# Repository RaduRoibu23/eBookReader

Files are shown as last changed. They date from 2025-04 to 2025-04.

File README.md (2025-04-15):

#  OpenBook E-Reader
---

## Prezentare Generala

**OpenBook** este un e-reader open-source, proiectat in jurul microcontrollerului **ESP32-C6**, gandit pentru eficienta energetica, modularitate si conectivitate moderna. Dispozitivul utilizeaza un ecran e-paper de **7.5”**, asa cum a fost ceurt in enunt.

Proiectul a fost realizat in conformitate cu cerintele specifice [proiectului TSC 2025](https://ocw.cs.pub.ro/courses/tsc/proiect2025), punand accent pe documentare clara, organizare modulara si integrarea eficienta a componentelor hardware si software.

Am investit aproximativ **35–40 de ore de lucru** in dezvoltarea acestuia pentru a-l aduce in forma actuala, timp in care am proiectat schema electronica si PCB-ul . Din pacate, din cauza unor probleme tehnice peste care nu am reusit sa trec in timp util, **nu am reusit sa finalizez partea de modelare 3D** a carcasei si ansamblului complet.

In ciuda acestui neajuns, consider ca proiectul reflecta un efort solid si o abordare completa in ceea ce priveste realizarea.

Poza Bottom
Poza Top
Routing

---

##  Diagrama de Bloc
```

                +---------------------------+
                |     USB-C Connector       |
                | (USB Data ↔ ESP32 USB)    |
                | (ESD & Termination Prot.) |
                +-------------+-------------+
                              |
                              v
                +--------------------------+
                |       Charging IC        |<-- USB-C Power
                +-------------+------------+
                              |
                              v
                +--------------------------+
                |         Battery          |
                +-------------+------------+
                              |
                              v
                +--------------------------+
                |           LDO            |
                |       (3.3V Reg)         |
                +-------------+------------+
                              |
                              v
                      +--------------+
                      |    ESP32-C6   |
                      +------+--------+
                             |
      +----------------------+-------------------------+
      |                      |                         |
      v                      v                         v
+-----------+       +----------------+         +-----------------+
|  Display  |<----->|     BME688     |<------->| Tactile Buttons |
| (SPI 4W)  |       |   (I2C + PU)   |         |  (GPIO + RC)     |
+-----------+       +----------------+         +-----------------+
```
Legend:
- PU = Pull-up resistors
- RC = Debouncing circuit

---

##  Arhitectura Hardware

###  ESP32-C6-WROOM-1-N8

- **Rol:** Controler principal
- **Frecventa:** 160 MHz
- **Memorie:** 512KB SRAM + 8MB Flash
- **Conectivitate:** Wi-Fi 6, Bluetooth 5, USB 2.0
- **Interfete:**
  - SPI: Display, Flash, MicroSD
  - I2C: Senzori si RTC
  - UART: Debug
  - GPIO: Butoane si LED-uri

###  Display E-Paper

- **Dimensiune:** 7.5 inch
- **Rezolutie:** 800×480 px
- **Consum:** <50mA activ, ~0 in standby
- **Interfata:** SPI
- 
###  Sistem Alimentare

- **Baterie:** Li-Po 3.7V / 2500mAh
- **Incarcare:** USB-C (5V, max. 1A) – MCP73831
- **Monitorizare:** MAX17048 (prin I2C)
- **Consum estimat:**
  - Activ (Wi-Fi + Display): ~150mA
  - Standby: ~10mA
  - Deep Sleep: <50µA
- **Autonomie:** ~250 ore (~1 saptamana)

### Navigare

- **Butoane:** Panasonic EVQPUJ02K
- **Rezistenta pull-up:** 10KΩ

### USB-C

- **Rol:** Alimentare si transfer de date
- **Protectie:** Diode ESD (USBLC6-2SC6Y)

---

##  Configuratie Pini ESP32-C6

| Pin | Functie | Componenta | Descriere |
|---|---|---|---|
| GPIO0 | BOOT_BUTTON | Buton | Init bootloader |
| GPIO1 | RESET_BUTTON | Buton | Reset sistem |
| GPIO2 | CHANGE_BUTTON | Buton | Navigare meniuri |
| GPIO3 | EPD_CS | Display | SPI Chip Select |
| GPIO4 | EPD_DC | Display | Date / Comenzi |
| GPIO5 | EPD_RST | Display | Reset display |
| GPIO6 | EPD_BUSY | Display | Status refresh |
| GPIO7 | SPI_MOSI | Flash, SD, Display  | Date SPI |
| GPIO8 | SPI_MISO | Flash, SD, Display  | Date SPI (read) |
| GPIO9 | SPI_SCK | Flash, SD, Display  | Ceas SPI |
| GPIO10  | FLASH_CS | Flash | SPI Chip Select |
| GPIO11  | SD_CS | Card SD | SPI Chip Select |
| GPIO12  | I2C_SDA | Senzori, RTC | Date I2C |
| GPIO13  | I2C_SCL | Senzori, RTC | Ceas I2C |
| GPIO14  | CHG_LED | LED | Indicator incarcare |
| GPIO15  | UART_TX | Debug | Serial TX |
| GPIO16  | UART_RX | Debug | Serial RX |
| GPIO17  | USB_D+ | USB-C | Linie USB pozitiva |
| GPIO18  | USB_D- | USB-C | Linie USB negativa |

---

## BOM:

| **Piece Name** | **Piece Type (Optional)** | **Link** |
|---|---|---|
| ESP32-CAP C0402 | C | https://componentsearchengine.com/part-view/CC0402MRX5R5BB106/YAGEO |
| ADAFRUIT_CHIP-LED0603 | LED | https://www.snapeda.com/parts/KP-1608SURCK/Kingbright/view-part/?ref=search&t=LED%200603 |
| 112ATAARR03 | microSD | https://www.snapeda.com/parts/112A-TAAR-R03/Attend/view-part/ |
| 744043680 | L | https://eu.mouser.com/ProductDetail/Wurth-Elektronik/744043680?qs=PGXP4M47uW6VkZq%252BkzjrHA%3D%3D |
| BD5229G-TR | Voltage Detector | https://www.snapeda.com/parts/BD5229G-TR/Rohm/view-part/?ref=search&t=BD5229G-TR |
| BUTTON_CUSYOMV1 | Button | https://www.snapeda.com/search/?q=EVQP7L01P&search-type=parts |
| CPH3225A | C | https://www.snapeda.com/parts/CPH3225A/Seiko/view-part/ |
| DS3231SN# | I²C-Integrated RTC/TCXO/Crystal | https://www.snapeda.com/parts/DS3231SN%23/Analog%20Devices/view-part/?ref=search&t=DS3231SN%23 |
| ESP32-C6-WROOM-1-N8 | ESP32 | https://www.snapeda.com/parts/ESP32-C6-WROOM-1-N8/Espressif%20Systems/view-part/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 |
| ESP VARSISTOR | Varsistor (B72520T0350K062) | https://ro.mouser.com/ProductDetail/EPCOS-TDK/B72520T0350K062?qs=dEfas%2FXlABIszF52uu7vrg%3D%3D |
| ESP32_WROVER_AVX---SD0805S020S1R0 |  DIODE SCHOTTKY | https://componentsearchengine.com/part-view/SD0805S020S1R0/Kyocera%20AVX |
| ESP32_WROVER_BME680_BME680 | Env Senzor | https://www.snapeda.com/parts/BME680/Bosch%20Sensortec/view-part/?ref=search&t=bme680 |
| ESP32_WROVER_EAGLE-LTSPICE_R | R | https://componentsearchengine.com/part-view/R0402%201%25%20100%20K%20(RC0402FR-07100KL)/YAGEO |
| ESP32_WROVER_SPARKFUN-DISCRETESEMI_MOSFET_PCH | T DMG2305UX-7 | https://componentsearchengine.com/part-view/DMG2305UX-7/Diodes%20Incorporated |
| ESP32_WROVER_SPARKFUN-IC-POWER_MCP73831 | TINY INTEGRATED LI-ION/LI-POLY CHARGE MGNT CONTROLLER | https://componentsearchengine.com/part-view/MCP73831T-2ACI%2FOT/Microchip |
| FH34SRJ-24S-0.5SH_99_ | FH34SRJ-24S-0.5SH(99) | https://componentsearchengine.com/part-view/FH34SRJ-24S-0.5SH(99)/Hirose |
| MAX17048G+T10 |  Cell Fuel Gauge with ModelGauge | https://www.snapeda.com/parts/MAX17048G+T10/Analog%20Devices/view-part/ |
| MBR0530 |  Diode Schottky | https://www.snapeda.com/parts/MBR0530/Onsemi/view-part/ |
| PGB1010603MR |  Ipp Tvs Diode Surface Mount 0603 | https://www.snapeda.com/parts/PGB1010603MR/Littelfuse/view-part/ |
| QWIIC_CONNECTOR | PRT-14417 QWIIC_CONNECTOR | https://www.snapeda.com/parts/PRT-14417/SparkFun/view-part/ |
| RCL_CPOL-EU | C pol | https://grabcad.com/library/tantalum-smd-capacitor-type-b-3528-1 |
| SAMACSYS_PARTS_USB4110-GF-A | USB4110-GF-A | https://www.snapeda.com/parts/USB4110-GF-A./Global%20Connector%20Technology/view-part/ |
| SJ | Jumper-SolderPasteJumper3way | https://grabcad.com/library/solder-jumpers-1 |
| TP | Test-Pad | self-made |
| SI1308EDL-T1-GE3 |  MOSFET Transistor | https://www.snapeda.com/parts/SI1308EDL-T1-GE3/Vishay/view-part/ |
| USBLC6-2SC6Y |  Ipp Tvs Diode Surface Mount | https://www.snapeda.com/parts/USBLC6-2SC6Y/STMicroelectronics/view-part/?ref=dk&t=USBLC6-2SC6Y&con_ref=None |
| W25Q512JVEIQ | FLASH - NOR Memory | https://www.snapeda.com/parts/W25Q512JVEIQ/Winbond%20Electronics/view-part/?ref=search&t=W25Q512JVEIQ |
| XC6220A331MR-G | Voltage Regulator | https://ro.mouser.com/ProductDetail/Torex-Semiconductor/XC6220A331MR-G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

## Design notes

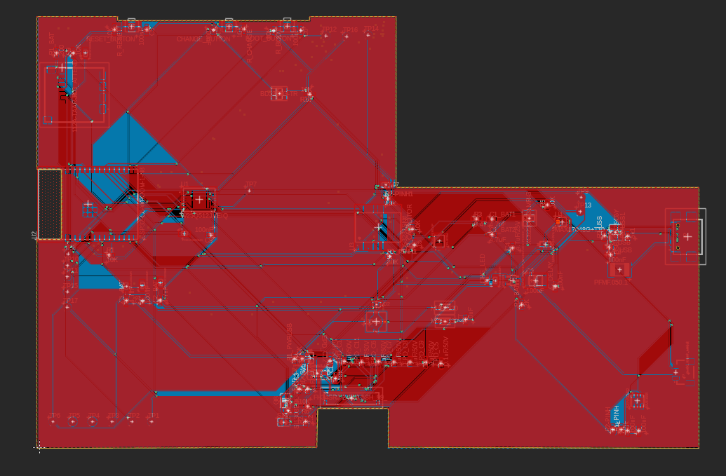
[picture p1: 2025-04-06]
Proiect TCS/Images/Poza Top.png

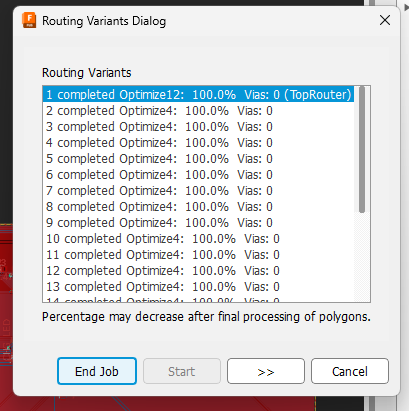
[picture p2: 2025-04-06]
Proiect TCS/Images/Routing .png

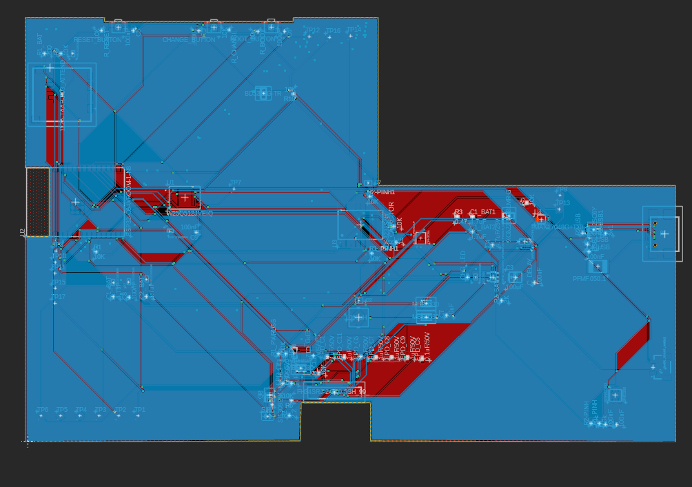
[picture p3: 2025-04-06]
Proiect TCS/Images/Poza Bottom.png

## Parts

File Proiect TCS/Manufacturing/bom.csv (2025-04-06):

Qty | Value | Device | Package | Parts | Description | ARROW_PART_NUMBER | ARROW_PRICE-STOCK | AVAILABILITY | CENTROID_NOT_SPECIFIED | CHECK_PRICES | COPYRIGHT | DATASHEET | DESCRIPTION | DIGIKEY_DESCRIPTION | DIGIKEY_PART_NUMBER | HEIGHT | LEAD_FREE | MANUFACTURER_NAME | MANUFACTURER_PART_NUMBER | MF | MFR_NAME | MOUSER_PART_NUMBER | MOUSER_PRICE-STOCK | MOUSER_TESTING_PART_NUMBER | MOUSER_TESTING_PRICE-STOCK | MP | MPN | PACKAGE | POPULARITY | PREFIX | PRICE | PROD_ID | PURCHASE-URL | ROHS | SNAPEDA_LINK | SPICEMODEL | SPICEPREFIX | TEMPERATURE_RANGE_HIGH | TEMPERATURE_RANGE_LOW | TP_SIGNAL_NAME | VALUE
1 |  | ADAFRUIT_LEDCHIP-LED0603 | ADAFRUIT_CHIP-LED0603 | CHG_LED | LED
1 |  | ESP32C6_VARISTORCN1812 | ESP32C6_VARISTOR_CT/CN1812 | PFMF.050.1 | VARISTOR |  |  |  |  |  |  |  |  |  |  |  |  |  |  |  |  |  |  |  |  |  |  |  | 0
1 |  | SAMACSYS_PARTS_USB4110-GF-A | SAMACSYS_PARTS_USB4110GFA | J2 | CONN USB 2.0 TYPE-C R/A SMT |  |  |  |  |  |  |  | CONN USB 2.0 TYPE-C R/A SMT |  |  | 3.26mm |  | GCT (GLOBAL CONNECTOR TECHNOLOGY) | USB4110-GF-A |  |  | 640-USB4110-GF-A | https://www.mouser.co.uk/ProductDetail/GCT/USB4110-GF-A?qs=KUoIvG%2F9IlYiZvIXQjyJeA%3D%3D
1 |  | SJ | SJ | SJ1 | SMD solder JUMPER |  |  |  |  |  |  |  |  |  |  |  |  |  |  |  |  |  |  |  |  |  |  |  | 3
1 | 0.1uF/50V | EAGLE-LTSPICE_CC0402 | EAGLE-LTSPICE_C0402 | EPD_C5 | CAPACITOR, European symbol |  |  |  |  |  |  |  |  |  |  |  |  |  |  |  |  |  |  |  |  |  |  |  |  |  |  |  |  |  |  | NONE | C
1 | 0.47 | ESP32_WROVER_EAGLE-LTSPICE_RR0402 | ESP32_WROVER_EAGLE-LTSPICE_R0402 | R3 | RESISTOR, European symbol |  |  |  |  |  |  |  |  |  |  |  |  |  |  |  |  |  |  |  |  |  |  |  |  |  |  |  |  |  |  | NONE | R
1 | 100K | ESP32_WROVER_EAGLE-LTSPICE_RR0402 | ESP32_WROVER_EAGLE-LTSPICE_R0402 | R1_PWRUSB | RESISTOR, European symbol |  |  |  |  |  |  |  |  |  |  |  |  |  |  |  |  |  |  |  |  |  |  |  |  |  |  |  |  |  |  | NONE | R
3 | 100nF | EAGLE-LTSPICE_CC0402 | EAGLE-LTSPICE_C0402 | C5, C6, C10 | CAPACITOR, European symbol |  |  |  |  |  |  |  |  |  |  |  |  |  |  |  |  |  |  |  |  |  |  |  |  |  |  |  |  |  |  | NONE | C
6 | 100nF | ESP32_WROVER_EAGLE-LTSPICE_CC0402 | ESP32_WROVER_EAGLE-LTSPICE_C0402 | C1, C2, C4_USB, C8, C9, C_DELAY | CAPACITOR, European symbol |  |  |  |  |  |  |  |  |  |  |  |  |  |  |  |  |  |  |  |  |  |  |  |  |  |  |  |  |  |  | NONE | C
1 | 100uF | RCL_CPOL-EUCT3528 | RCL_CT3528 | C3 | POLARIZED CAPACITOR, European symbol |  |  |  |  |  |  |  |  |  |  |  |  |  |  |  |  |  |  |  |  |  |  |  | 0 |  |  |  |  |  |  |  | C
14 | 10K | ESP32_WROVER_EAGLE-LTSPICE_RR0402 | ESP32_WROVER_EAGLE-LTSPICE_R0402 | R1, R1_PINH1, R2-PINH1, R4, R5, R6, R7, R8, R9, R10, R_BOOT, R_CHANGE, R_CL1, R_RESET | RESISTOR, European symbol |  |  |  |  |  |  |  |  |  |  |  |  |  |  |  |  |  |  |  |  |  |  |  |  |  |  |  |  |  |  | NONE | R
2 | 10k | ESP32_WROVER_EAGLE-LTSPICE_RR0402 | ESP32_WROVER_EAGLE-LTSPICE_R0402 | R1_PINH, R2-PINH | RESISTOR, European symbol |  |  |  |  |  |  |  |  |  |  |  |  |  |  |  |  |  |  |  |  |  |  |  |  |  |  |  |  |  |  | NONE | R
1 | 10uF | ESP32_WROVER_EAGLE-LTSPICE_CC0402 | ESP32_WROVER_EAGLE-LTSPICE_C0402 | C7 | CAPACITOR, European symbol |  |  |  |  |  |  |  |  |  |  |  |  |  |  |  |  |  |  |  |  |  |  |  |  |  |  |  |  |  |  | NONE | C
1 | 112A-TAAR-R03_ATTEND | 112A-TAAR-R03_ATTEND | 112ATAARR03ATTEND | J4 | Micro SD Card Socket, Push-Push Type, Top Mount, SMT, H=1.83mm, 10u |  |  |  |  |  |  |  | Micro SD Card Socket | Push-Push Type | Top Mount | SMT | H=1.83mm | 10u |  |  | 1.9mm |  | ATTEND | 112A-TAAR-R03 ATTEND
1 | 15 | ESP32_WROVER_EAGLE-LTSPICE_RR0402 | ESP32_WROVER_EAGLE-LTSPICE_R0402 | R_CAPACITOR | RESISTOR, European symbol |  |  |  |  |  |  |  |  |  |  |  |  |  |  |  |  |  |  |  |  |  |  |  |  |  |  |  |  |  |  | NONE | R
9 | 1uF/50V | EAGLE-LTSPICE_CC0402 | EAGLE-LTSPICE_C0402 | EPD_C1, EPD_C2, EPD_C6, EPD_C7, EPD_C8, EPD_C9, EPD_C10, EPD_C11, EPD_C12 | CAPACITOR, European symbol |  |  |  |  |  |  |  |  |  |  |  |  |  |  |  |  |  |  |  |  |  |  |  |  |  |  |  |  |  |  | NONE | C
1 | 2.2 | ESP32_WROVER_EAGLE-LTSPICE_RR0402 | ESP32_WROVER_EAGLE-LTSPICE_R0402 | R2 | RESISTOR, European symbol |  |  |  |  |  |  |  |  |  |  |  |  |  |  |  |  |  |  |  |  |  |  |  |  |  |  |  |  |  |  | NONE | R
1 | 200 | ESP32_WROVER_EAGLE-LTSPICE_RR0402 | ESP32_WROVER_EAGLE-LTSPICE_R0402 | R1_BAT | RESISTOR, European symbol |  |  |  |  |  |  |  |  |  |  |  |  |  |  |  |  |  |  |  |  |  |  |  |  |  |  |  |  |  |  | NONE | R
2 | 20V/4.2A/52mO/1.4W | ESP32_WROVER_SPARKFUN-DISCRETESEMI_MOSFET_PCH-DMG2305UX-7 | ESP32_WROVER_SPARKFUN-DISCRETESEMI_SOT23-3 | Q1, Q2 | P-channel MOSFETs |  |  |  |  |  |  |  |  |  |  |  |  |  |  |  |  |  |  |  |  |  |  |  |  |  |  | TRAN-14388 |  |  |  |  |  |  |  |  | 20V/4.2A/52mO/1.4W
1 | 2K | ESP32_WROVER_EAGLE-LTSPICE_RR0402 | ESP32_WROVER_EAGLE-LTSPICE_R0402 | R2_BAT | RESISTOR, European symbol |  |  |  |  |  |  |  |  |  |  |  |  |  |  |  |  |  |  |  |  |  |  |  |  |  |  |  |  |  |  | NONE | R
5 | 4.7uF | ESP32_WROVER_EAGLE-LTSPICE_CC0402 | ESP32_WROVER_EAGLE-LTSPICE_C0402 | C1_BAT, C1_BAT1, C1_BAT2, C2_BAT, C5_USB | CAPACITOR, European symbol |  |  |  |  |  |  |  |  |  |  |  |  |  |  |  |  |  |  |  |  |  |  |  |  |  |  |  |  |  |  | NONE | C
1 | 4.7uF/25V | ESP32_WROVER_EAGLE-LTSPICE_CC0402 | ESP32_WROVER_EAGLE-LTSPICE_C0402 | C4 | CAPACITOR, European symbol |  |  |  |  |  |  |  |  |  |  |  |  |  |  |  |  |  |  |  |  |  |  |  |  |  |  |  |  |  |  | NONE | C
2 | 5k1 | ESP32_WROVER_EAGLE-LTSPICE_RR0402 | ESP32_WROVER_EAGLE-LTSPICE_R0402 | R2-USB, R2-USB1 | RESISTOR, European symbol |  |  |  |  |  |  |  |  |  |  |  |  |  |  |  |  |  |  |  |  |  |  |  |  |  |  |  |  |  |  | NONE | R
1 | 68uH | 744043680IND_4828-WE-TPC_WRE | IND_4828-WE-TPC_WRE | L1 |  |  |  |  |  |  | Copyright (C) 2024 Ultra Librarian. All rights reserved. |  |  |  |  |  |  |  | 744043680 |  | Wurth Electronics
1 | BD5229G-TR | BD5229G-TR | SOT95P280X125-5N | IC1 | Voltage Detector with Adjustable Delay Time: CMOS processes are utilized to develop high precision, low current consumption CMOS reset ICs that allow arbitrary setting of the delay time. The extensive lineup includes both Nch Open Drain and CMOS output types in a wide range of detection voltages (from 2.3V to 6.0V, in 0.1V steps), enabling selection of the ideal solution based on customer requirements. In addition, the entire series is of course both lead-free and RoHS-compliant. |  |  |  |  |  |  |  | Voltage Detector with Adjustable Delay Time: CMOS processes are utilized to develop high precision | low current consumption CMOS reset ICs that allow arbitrary setting of the delay time. The extensive lineup includes both Nch Open Drain and CMOS output types in a wide range of detection voltages (from 2.3V to 6.0V | in 0.1V steps) | enabling selection of the ideal solution based on customer requirements. In addition | the entire series is of course both lead-free and RoHS-compliant. |  |  | 1.25mm |  | ROHM Semiconductor | BD5229G-TR |  |  | 755-BD5229G-TR | https://www.mouser.co.uk/ProductDetail/ROHM-Semiconductor/BD5229G-TR?qs=4kLU8WoGk0vvnhrrYwdszw%3D%3D
1 | BME688 | ESP32_WROVER_BME680_BME680 | ESP32_WROVER_BME680_PSON80P300X300X100-8N | SENSOR2 | Integrated Environmental Unit |  |  | Unavailable |  |  |  |  | Integrated Environmental Unit |  |  |  |  |  |  | Bosch Sensortec |  |  |  |  |  | BME680 |  | LGA-8 Bosch Tools |  |  | None
3 | BUTTON_CUSYOMV1 | BUTTON_CUSYOMV1 | MYBUTTON | BOOT_BUTTON, CHANGE_BUTTON, RESET_BUTTON
1 | CPH3225A | CPH3225A | CAPCP3225X100N | C10_SUPERCAP | Cap 0.011F 3.3V 1210 Flat Check availability |  |  | Not in stock |  | https://www.snapeda.com/parts/CPH3225A/Seiko+Instruments/view-part/?ref=eda |  |  | 11 mF (EDLC) Supercapacitor 3.3 V 1210 (3225 Metric) - - |  |  |  |  |  |  | Seiko Instruments |  |  |  |  |  | CPH3225A |  | 1210 Seiko |  |  | None |  | https://www.snapeda.com/api/url_track_click_mouser/?unipart_id=562593&manufacturer=Seiko Instruments&part_name=CPH3225A&search_term=None |  | https://www.snapeda.com/parts/CPH3225A/Seiko+Instruments/view-part/?ref=snap
1 | DS3231SN# | DS3231SN# | SOIC127P1032X265-16N | U3 | Real Time Clock Serial 16-Pin SOIC W T/R Check availability |  |  | In Stock |  | https://www.snapeda.com/parts/DS3231SN%23/Analog+Devices/view-part/?ref=eda |  |  | Extremely Accurate I²C-Integrated RTC/TCXO/Crystal |  |  |  |  |  |  | Analog Devices |  |  |  |  |  | DS3231SN# |  | SOIC-16 Maxim |  |  | None |  | https://www.snapeda.com/api/url_track_click_mouser/?unipart_id=99048&manufacturer=Analog Devices&part_name=DS3231SN#&search_term=None |  | https://www.snapeda.com/parts/DS3231SN%23/Analog+Devices/view-part/?ref=snap
1 | ESP32-C6-WROOM-1-N8 | ESP32-C6-WROOM-1-N8 | XCVR_ESP32-C6-WROOM-1-N8 | U2 | Check availability |  |  | In Stock |  | https://www.snapeda.com/parts/ESP32-C6-WROOM-1-N8/Espressif+Systems/view-part/?ref=eda |  |  | Multiprotocol Modules ESP32-C6 module | Wi-Fi 6 in 2.4 GHz band | Bluetooth 5 | Zigbee 3.0 and Thread. ESP34-WROOM Compatible - ENGINEERING SAMPLE |  |  |  |  |  |  | Espressif Systems |  |  |  |  |  | ESP32-C6-WROOM-1-N8 |  | None |  |  | None |  |  |  | https://www.snapeda.com/parts/ESP32-C6-WROOM-1-N8/Espressif+Systems/view-part/?ref=snap
2 | ESP32_WROVER_AVX---SD0805S020S1R0_AVX_SD0805S020S1R0_0_0AVX_SD0805S020S1R0_0_0 | ESP32_WROVER_AVX---SD0805S020S1R0_AVX_SD0805S020S1R0_0_0AVX_SD0805S020S1R0_0_0 | ESP32_WROVER_AVX---SD0805S020S1R0_AVX_SD0805S020S1R0_0 | D2, D7 | Schottky Barrier Rectifier Diode |  |  |  | No |  |  | http://datasheets.avx.com/schottky.pdf |  | DIODE SCHOTTKY 20V 1A 0805 | 478-7800-1-ND |  | yes |  |  | AVX |  | 581-SD0805S020S1R0 |  |  |  |  |  | 0805 (2012 metric) |  | D |  |  |  | yes |  |  |  | +125°C | -55°C
1 | ESP32_WROVER_SPARKFUN-IC-POWER_MCP73831 | ESP32_WROVER_SPARKFUN-IC-POWER_MCP73831 | ESP32_WROVER_SPARKFUN-IC-POWER_SOT23-5 | MCP73831 | MCP73831T Li-Ion, Li-Pol Controller |  |  |  |  |  |  |  |  |  |  |  |  |  |  |  |  |  |  |  |  |  |  |  |  |  |  | IC-09995
1 | FH34SRJ-24S-0.5SH_99_ | FH34SRJ-24S-0.5SH_99_ | FH34SRJ24S05SH99 | J1 | (0.50mm) Surface Mount, Right Angle |  |  |  |  |  |  |  | 24 Position FFC | FPC Connector Contacts | (0.50mm) Surface Mount | Right Angle |  |  | 1.1mm |  | Hirose | FH34SRJ-24S-0.5SH(99) |  |  | 798-FH34SRJ24S05SH99 | https://www.mouser.co.uk/ProductDetail/Hirose-Connector/FH34SRJ-24S-0.5SH99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
1 | MAX17048G+T10 | MAX17048G+T10 | SON50P200X200X80-9N | U4 | Check availability |  |  | In Stock |  | https://www.snapeda.com/parts/MAX17048G+T10/Analog+Devices/view-part/?ref=eda |  |  | 3µA 1-Cell/2-Cell Fuel Gauge with ModelGauge |  |  |  |  |  |  | Analog Devices |  |  |  |  |  | MAX17048G+T10 |  | TDFN-8 Maxim |  |  | None |  | https://www.snapeda.com/api/url_track_click_mouser/?unipart_id=329239&manufacturer=Analog Devices&part_name=MAX17048G+T10&search_term=None |  | https://www.snapeda.com/parts/MAX17048G+T10/Analog+Devices/view-part/?ref=snap
3 | MBR0530 | MBR0530 | SOD3716X135N | D3, D4, D5 | ON SEMICONDUCTOR - MBR0530 - DIODE, SCHOTTKY, 0.5A, 30V, SOD-123 |  |  | In Stock |  | https://www.snapeda.com/parts/MBR0530/Onsemi/view-part/?ref=eda |  |  | Diode Schottky 30 V 500mA Surface Mount SOD-123 |  |  |  |  |  |  | ON Semiconductor |  |  |  |  |  | MBR0530 |  | SOD-123-2 ON Semiconductor |  |  | None |  | https://www.snapeda.com/api/url_track_click_mouser/?unipart_id=179458&manufacturer=ON Semiconductor&part_name=MBR0530&search_term=None |  | https://www.snapeda.com/parts/MBR0530/Onsemi/view-part/?ref=snap
6 | PGB1010603MR | PGB1010603MR | DIOC1608X36N | D6, D8, D9, D10, D11, D12 | Check availability |  |  | In Stock |  | https://www.snapeda.com/parts/PGB1010603MR/Littelfuse/view-part/?ref=eda |  |  | 150V (Typ) Clamp - Ipp Tvs Diode Surface Mount 0603 (1608 Metric) |  |  |  |  |  |  | Littelfuse Inc. |  |  |  |  |  | PGB1010603MR |  | 0603 Littelfuse Inc. |  |  | None |  | https://www.snapeda.com/api/url_track_click_mouser/?unipart_id=5659453&manufacturer=Littelfuse Inc.&part_name=PGB1010603MR&search_term=None |  | https://www.snapeda.com/parts/PGB1010603MR/Littelfuse/view-part/?ref=snap
1 | QWIIC_RIGHT_ANGLE | QWIIC_CONNECTORJS-1MM | JST04_1MM_RA | J3 | SparkFun I2C Standard Qwiic Connector |  |  |  |  |  |  |  |  |  |  |  |  |  |  |  |  |  |  |  |  |  |  |  |  |  |  | CONN-13694 |  |  |  |  |  |  |  |  | QWIIC_RIGHT_ANGLE
1 | SI1308EDL-T1-GE3 | SI1308EDL-T1-GE3 | SOT65P210X110-3N | Q3 | MOSFET N-Ch 30V 1.5A TrenchFET SC70 Vishay Si1308EDL-T1-GE3 N-channel MOSFET Transistor, 1.5 A, 30 V, 3-Pin SC-70 |  |  | In Stock |  | https://www.snapeda.com/parts/SI1308EDL-T1-GE3/Vishay+Siliconix/view-part/?ref=eda |  |  | Si1308EDL-T1-GE3 N-channel MOSFET Transistor | 1.5 A | 30 V | 3-Pin SC-70 | Siliconix / Vishay SI1308EDL-T1-GE3 |  |  |  |  |  |  | Vishay Siliconix |  |  |  |  |  | SI1308EDL-T1-GE3 |  | SOT-323 Vishay Semiconductor |  |  | None |  | https://www.snapeda.com/api/url_track_click_mouser/?unipart_id=274603&manufacturer=Vishay Siliconix&part_name=SI1308EDL-T1-GE3&search_term=None |  | https://www.snapeda.com/parts/SI1308EDL-T1-GE3/Vishay+Siliconix/view-part/?ref=snap
17 | TPTP20R | TPTP20R | TP20R | TP1, TP2, TP3, TP4, TP5, TP6, TP7, TP8, TP9, TP10, TP11, TP12, TP13, TP14, TP15, TP16, TP17 | Test pad |  |  |  |  |  |  |  |  |  |  |  |  |  |  |  |  |  |  |  |  |  |  |  | 2
1 | USBLC6-2SC6Y | USBLC6-2SC6Y | SOT95P280X145-6N | D1 | Low Cap. ESD Protection Auto SOT-23-6 STMicroelectronics USBLC6-2SC6Y, Dual Uni-Directional TVS Diode Array, 6-Pin SOT-23 |  |  | In Stock |  | https://www.snapeda.com/parts/USBLC6-2SC6Y/STMicroelectronics/view-part/?ref=eda |  |  | 17V Clamp 5A (8/20µs) Ipp Tvs Diode Surface Mount SOT-23-6 |  |  |  |  |  |  | STMicroelectronics |  |  |  |  |  | USBLC6-2SC6Y |  | SOT-23-6 STMicroelectronics |  |  | None |  |  |  | https://www.snapeda.com/parts/USBLC6-2SC6Y/STMicroelectronics/view-part/?ref=snap
1 | W25Q512JVEIQ | W25Q512JVEIQ | SON127P600X800X80-9N | U1 | Check availability |  |  | In Stock |  | https://www.snapeda.com/parts/W25Q512JVEIQ/Winbond+Electronics/view-part/?ref=eda |  |  | FLASH - NOR Memory IC 512Mb (64M x 8) SPI - Quad I/O 133 MHz 8-WSON (8x6) |  |  |  |  |  |  | Winbond Electronics |  |  |  |  |  | W25Q512JVEIQ |  | Package |  |  | None |  |  |  | https://www.snapeda.com/parts/W25Q512JVEIQ/Winbond+Electronics/view-part/?ref=snap
1 | XC6220A331MR-G | XC6220A331MR-G | SOT95P280X120-5N | IC4 | LDO Voltage Regulators |  |  |  |  |  |  |  | LDO Voltage Regulators |  |  | 1.2mm |  | Torex | XC6220A331MR-G |  |  | 865-XC6220A331MR-G | https://www.mouser.co.uk/ProductDetail/Torex-Semiconductor/XC6220A331MR-G?qs=AsjdqWjXhJ8ZSWznL1J0gg%3D%3D

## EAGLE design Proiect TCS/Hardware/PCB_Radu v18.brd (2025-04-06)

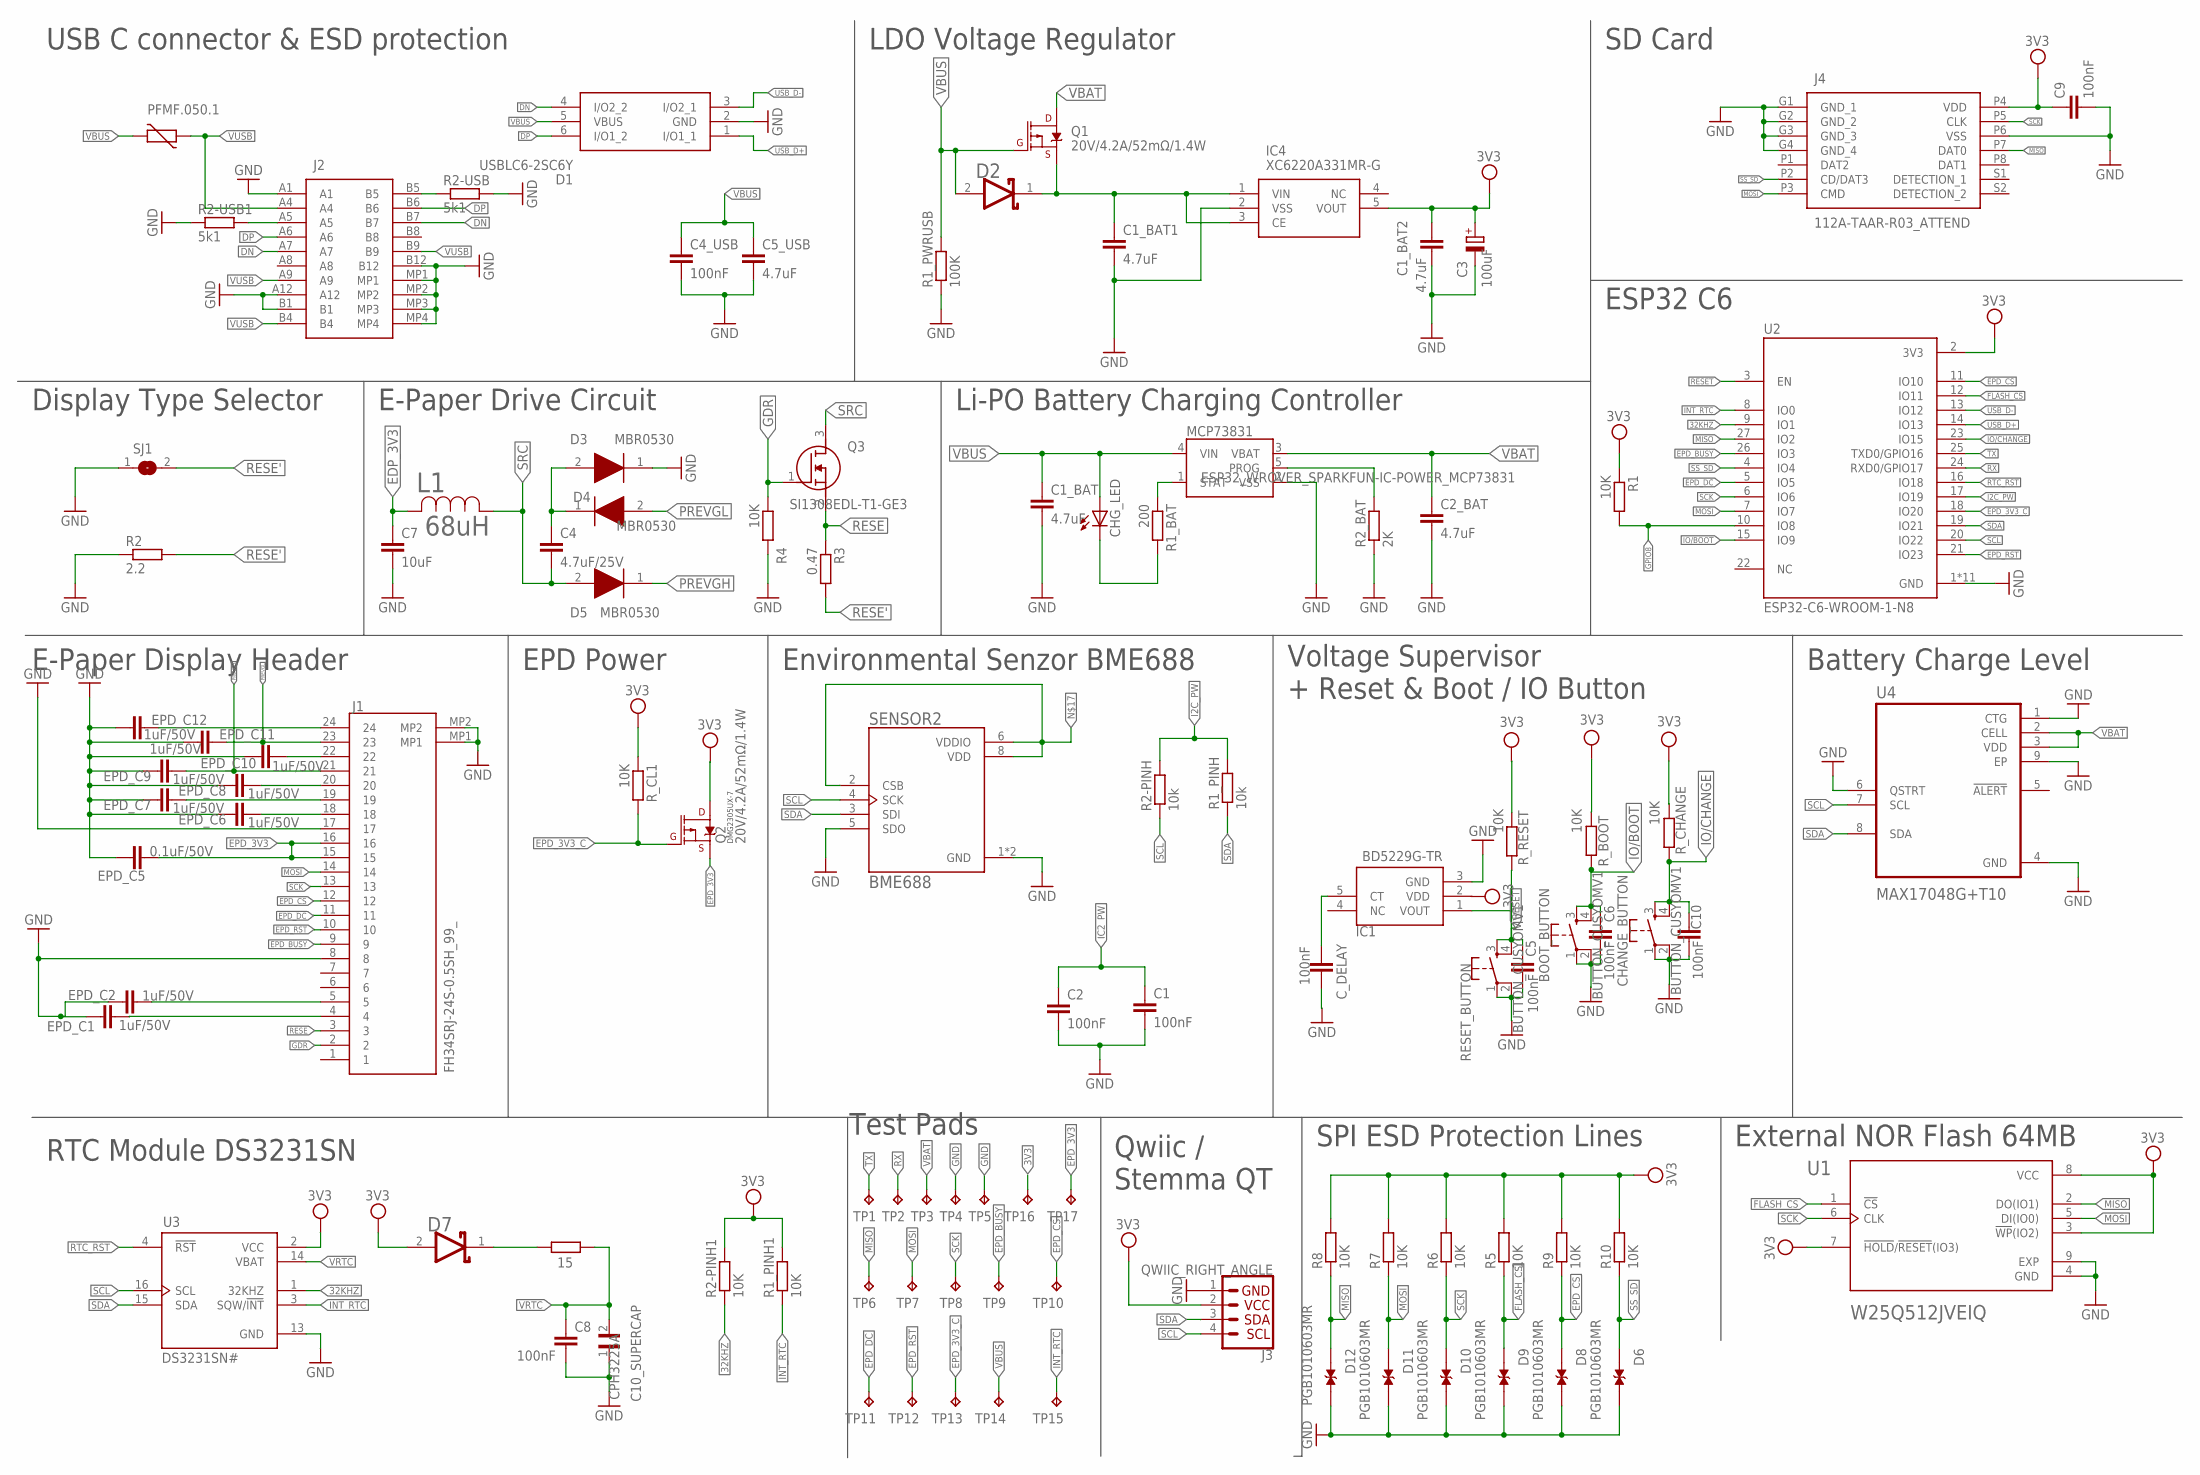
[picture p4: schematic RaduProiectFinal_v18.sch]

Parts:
BOOT_BUTTON: BUTTON_CUSYOMV1; MYBUTTON
C1, C2, C4_USB, C8, C9: 100nF; ESP32_WROVER_EAGLE-LTSPICE_C0402
C1_BAT, C1_BAT1, C1_BAT2, C2_BAT, C5_USB: 4.7uF; ESP32_WROVER_EAGLE-LTSPICE_C0402
C3: 100uF; RCL_CT3528
C4: 4.7uF/25V; ESP32_WROVER_EAGLE-LTSPICE_C0402
C5, C6, C10: 100nF; EAGLE-LTSPICE_C0402
C7: 10uF; ESP32_WROVER_EAGLE-LTSPICE_C0402
C10_SUPERCAP: CPH3225A; CAPCP3225X100N
CHANGE_BUTTON: BUTTON_CUSYOMV1; MYBUTTON
CHG_LED: ADAFRUIT_LEDCHIP-LED0603; ADAFRUIT_CHIP-LED0603
C_DELAY: 100nF; ESP32_WROVER_EAGLE-LTSPICE_C0402
D1: USBLC6-2SC6Y; SOT95P280X145-6N
D2, D7: ESP32_WROVER_AVX---SD0805S020S1R0_AVX_SD0805S020S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; ESP32_WROVER_AVX---SD0805S020S1R0_AVX_SD0805S020S1R0_0
D3, D4, D5: MBR0530; SOD3716X135N
D6, D8, D9, D10, D11, D12: PGB1010603MR; DIOC1608X36N
EPD_C1, EPD_C2, EPD_C6, EPD_C7, EPD_C8, EPD_C9, EPD_C10, EPD_C11, EPD_C12: 1uF/50V; EAGLE-LTSPICE_C0402
EPD_C5: 0.1uF/50V; EAGLE-LTSPICE_C0402
IC1: BD5229G-TR; SOT95P280X125-5N
IC4: XC6220A331MR-G; SOT95P280X120-5N
J1: FH34SRJ-24S-0.5SH_99_; FH34SRJ24S05SH99
J2: SAMACSYS_PARTS_USB4110-GF-A; SAMACSYS_PARTS_USB4110GFA
J3: QWIIC_RIGHT_ANGLE; JST04_1MM_RA
J4: 112A-TAAR-R03_ATTEND; 112ATAARR03ATTEND
L1: 68uH; IND_4828-WE-TPC_WRE
MCP73831: ESP32_WROVER_SPARKFUN-IC-POWER_MCP73831; ESP32_WROVER_SPARKFUN-IC-POWER_SOT23-5
PFMF.050.1: ESP32C6_VARISTORCN1812; ESP32C6_VARISTOR_CT/CN1812
Q1, Q2: 20V/4.2A/52mΩ/1.4W; ESP32_WROVER_SPARKFUN-DISCRETESEMI_SOT23-3
Q3: SI1308EDL-T1-GE3; SOT65P210X110-3N
R1, R1_PINH1, R2-PINH1, R4, R5, R6, R7, R8, R9, R10: 10K; ESP32_WROVER_EAGLE-LTSPICE_R0402
R1_BAT: 200; ESP32_WROVER_EAGLE-LTSPICE_R0402
R1_PINH, R2-PINH: 10k; ESP32_WROVER_EAGLE-LTSPICE_R0402
R1_PWRUSB: 100K; ESP32_WROVER_EAGLE-LTSPICE_R0402
R2: 2.2; ESP32_WROVER_EAGLE-LTSPICE_R0402
R2-USB, R2-USB1: 5k1; ESP32_WROVER_EAGLE-LTSPICE_R0402
R2_BAT: 2K; ESP32_WROVER_EAGLE-LTSPICE_R0402
R3: 0.47; ESP32_WROVER_EAGLE-LTSPICE_R0402
RESET_BUTTON: BUTTON_CUSYOMV1; MYBUTTON
R_BOOT: 10K; ESP32_WROVER_EAGLE-LTSPICE_R0402
R_CAPACITOR: 15; ESP32_WROVER_EAGLE-LTSPICE_R0402
R_CHANGE: 10K; ESP32_WROVER_EAGLE-LTSPICE_R0402
R_CL1: 10K; ESP32_WROVER_EAGLE-LTSPICE_R0402
R_RESET: 10K; ESP32_WROVER_EAGLE-LTSPICE_R0402
SENSOR2: BME688; ESP32_WROVER_BME680_PSON80P300X300X100-8N
SJ1: SJ
TP1, TP2, TP3, TP4, TP5, TP6, TP7, TP8, TP9, TP10, TP11, TP12, TP13, TP14, TP15, TP16, TP17: TPTP20R; TP20R
U1: W25Q512JVEIQ; SON127P600X800X80-9N
U2: ESP32-C6-WROOM-1-N8; XCVR_ESP32-C6-WROOM-1-N8
U3: DS3231SN#; SOIC127P1032X265-16N
U4: MAX17048G+T10; SON50P200X200X80-9N

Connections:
3V3: C1_BAT2.1, C3.+, C9.1, D7.2 (ANODE), IC4.5 (VOUT), J3.2, J4.P4 (VDD), Q2.3 (D), R1.1, R1_PINH1.2, R2-PINH1.2, R5.2, R6.2, R7.2, R8.2, R9.2, R10.2, R_BOOT.2, R_CHANGE.2, R_CL1.1, R_RESET.2, TP16.TP, U1.3 (!WP!(IO2)), U1.7 (!HOLD!/!RESET!(IO3)), U1.8 (VCC), U2.2 (3V3), U3.2 (VCC)
32KHZ: R2-PINH1.1, U2.9 (IO1), U3.1 (32KHZ)
DN: D1.4 (I/O2_2), J2.A7, J2.B7
DP: D1.6 (I/O1_2), J2.A6, J2.B6
EDP_3V3: C7.1, L1.2
EPD_3V3: EPD_C5.2, J1.15, J1.16, Q2.2 (S), TP17.TP
EPD_3V3_C: Q2.1 (G), R_CL1.2, TP13.TP, U2.18 (IO20)
EPD_BUSY: J1.9, TP9.TP, U2.26 (IO3)
EPD_CS: D8.1, J1.12, R9.1, TP10.TP, U2.11 (IO10)
EPD_DC: J1.11, TP11.TP, U2.5 (IO5)
EPD_RST: J1.10, TP12.TP, U2.21 (IO23)
FLASH_CS: D9.1, R5.1, U1.1 (!CS), U2.12 (IO11)
GDR: J1.2, Q3.1 (G), R4.1
GND: BOOT_BUTTON.1, BOOT_BUTTON.2, C1.2, C1_BAT.2, C1_BAT1.2, C1_BAT2.2, C2.2, C2_BAT.2, C3.-, C4_USB.2, C5.2, C5_USB.2, C6.2, C7.2, C8.2, C9.2, C10.2, C10_SUPERCAP.1, CHANGE_BUTTON.1, CHANGE_BUTTON.2, C_DELAY.2, D1.2 (GND), D3.1 (K), D6.2, D8.2, D9.2, D10.2, D11.2, D12.2, EPD_C1.1, EPD_C2.1, EPD_C5.1, EPD_C6.1, EPD_C7.1, EPD_C8.1, EPD_C9.1, EPD_C10.1, EPD_C11.1, EPD_C12.1, IC1.3 (GND), IC4.2 (VSS), J1.8, J1.17, J1.MP1, J1.MP2, J2.A1, J2.A12, J2.B1, J2.B12, J2.MP1, J2.MP2, J2.MP3, J2.MP4, J3.1, J4.G1 (GND_1), J4.G2 (GND_2), J4.G3 (GND_3), J4.G4 (GND_4), J4.P6 (VSS), MCP73831.2 (VSS), R1_PWRUSB.1, R2.1, R2-USB.2, R2-USB1.1, R2_BAT.1, R4.2, RESET_BUTTON.1, RESET_BUTTON.2, SENSOR2.1 (GND), SENSOR2.5 (SDO), SENSOR2.7 (GND), SJ1.1, TP4.TP, TP5.TP, U1.4 (GND), U1.9 (EXP), U2.1 (GND), U2.28 (GND), U2.29_1 (GND), U2.29_2 (GND), U2.29_3 (GND), U2.29_4 (GND), U2.29_5 (GND), U2.29_6 (GND), U2.29_7 (GND), U2.29_8 (GND), U2.29_9 (GND), U3.13 (GND), U4.1 (CTG), U4.4 (GND), U4.6 (QSTRT), U4.9 (EP)
GPIO8: R1.2, U2.10 (IO8)
I2C_PW: R1_PINH.2, R2-PINH.2, U2.17 (IO19)
IC2_PW: C1.1, C2.1
INT_RTC: R1_PINH1.1, TP15.TP, U2.8 (IO0), U3.3 (SQW/!INT)
IO/BOOT: BOOT_BUTTON.3, BOOT_BUTTON.4, C6.1, R_BOOT.1, U2.15 (IO9)
IO/CHANGE: C10.1, CHANGE_BUTTON.3, CHANGE_BUTTON.4, R_CHANGE.1, U2.23 (IO15)
MISO: D12.1, J4.P7 (DAT0), R8.1, TP6.TP, U1.2 (DO(IO1)), U2.27 (IO2)
MOSI: D11.1, J1.14, J4.P3 (CMD), R7.1, TP7.TP, U1.5 (DI(IO0)), U2.7 (IO7)
unnamed: EPD_C10.2, J1.22
unnamed: C1_BAT1.1, D2.1 (CATHODE), IC4.1 (VIN), IC4.3 (CE), Q1.2 (S)
unnamed: MCP73831.5 (PROG), R2_BAT.2
unnamed: EPD_C8.2, J1.20
unnamed: J2.B5, R2-USB.1
unnamed: C4.1, D3.2 (A), D4.1 (K)
unnamed: MCP73831.1 (STAT), R1_BAT.1
unnamed: CHG_LED.C, R1_BAT.2
unnamed: EPD_C7.2, J1.19
unnamed: J2.A5, R2-USB1.2
unnamed: EPD_C6.2, J1.18
unnamed: EPD_C12.2, J1.24
unnamed: D7.1 (CATHODE), R_CAPACITOR.2
unnamed: EPD_C2.2, J1.5
unnamed: EPD_C1.2, J1.4
unnamed: SENSOR2.2 (CSB), SENSOR2.6 (VDDIO), SENSOR2.8 (VDD)
unnamed: C_DELAY.1, IC1.5 (CT)
PREVGH: D5.1 (K), EPD_C9.2, J1.21
PREVGL: D4.2 (A), EPD_C11.2, J1.23
RESE: J1.3, Q3.2 (S), R3.1
RESE': R2.2, R3.2, SJ1.2
RESET: C5.1, IC1.1 (VOUT), RESET_BUTTON.3, RESET_BUTTON.4, R_RESET.1, U2.3 (EN)
RTC_RST: U2.16 (IO18), U3.4 (!RST)
RX: TP2.TP, U2.24 (RXD0/GPIO17)
SCK: D10.1, J1.13, J4.P5 (CLK), R6.1, TP8.TP, U1.6 (CLK), U2.6 (IO6)
SCL: J3.4, R2-PINH.1, SENSOR2.4 (SCK), U2.20 (IO22), U3.16 (SCL), U4.7 (SCL)
SDA: J3.3, R1_PINH.1, SENSOR2.3 (SDI), U2.19 (IO21), U3.15 (SDA), U4.8 (SDA)
SRC: C4.2, D5.2 (A), L1.1, Q3.3 (D)
SS_SD: D6.1, J4.P2 (CD/DAT3), R10.1, U2.4 (IO4)
TX: TP1.TP, U2.25 (TXD0/GPIO16)
USB_D+: D1.1 (I/O1_1), U2.14 (IO13)
USB_D-: D1.3 (I/O2_1), U2.13 (IO12)
VBAT: C2_BAT.1, MCP73831.3 (VBAT), Q1.3 (D), TP3.TP, U4.2 (CELL), U4.3 (VDD)
VBUS: C1_BAT.1, C4_USB.1, C5_USB.1, CHG_LED.A, D1.5 (VBUS), D2.2 (ANODE), MCP73831.4 (VIN), PFMF.050.1.2, Q1.1 (G), R1_PWRUSB.2, TP14.TP
VRTC: C8.1, C10_SUPERCAP.2, R_CAPACITOR.1, U3.14 (VBAT)
VUSB: J2.A4, J2.A9, J2.B4, J2.B9, PFMF.050.1.1

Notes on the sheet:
USB C connector & ESD protection
LDO Voltage Regulator
SD Card
ESP32 C6
Li-PO Battery Charging Controller
Display Type Selector
E-Paper Drive Circuit
Battery Charge Level
External NOR Flash 64MB
E-Paper Display Header
EPD Power
Environmental Senzor BME688
Voltage Supervisor + Reset & Boot / IO Button
RTC Module DS3231SN
Qwiic / Stemma QT
Test Pads
SPI ESD Protection Lines
DMG2305UX-7

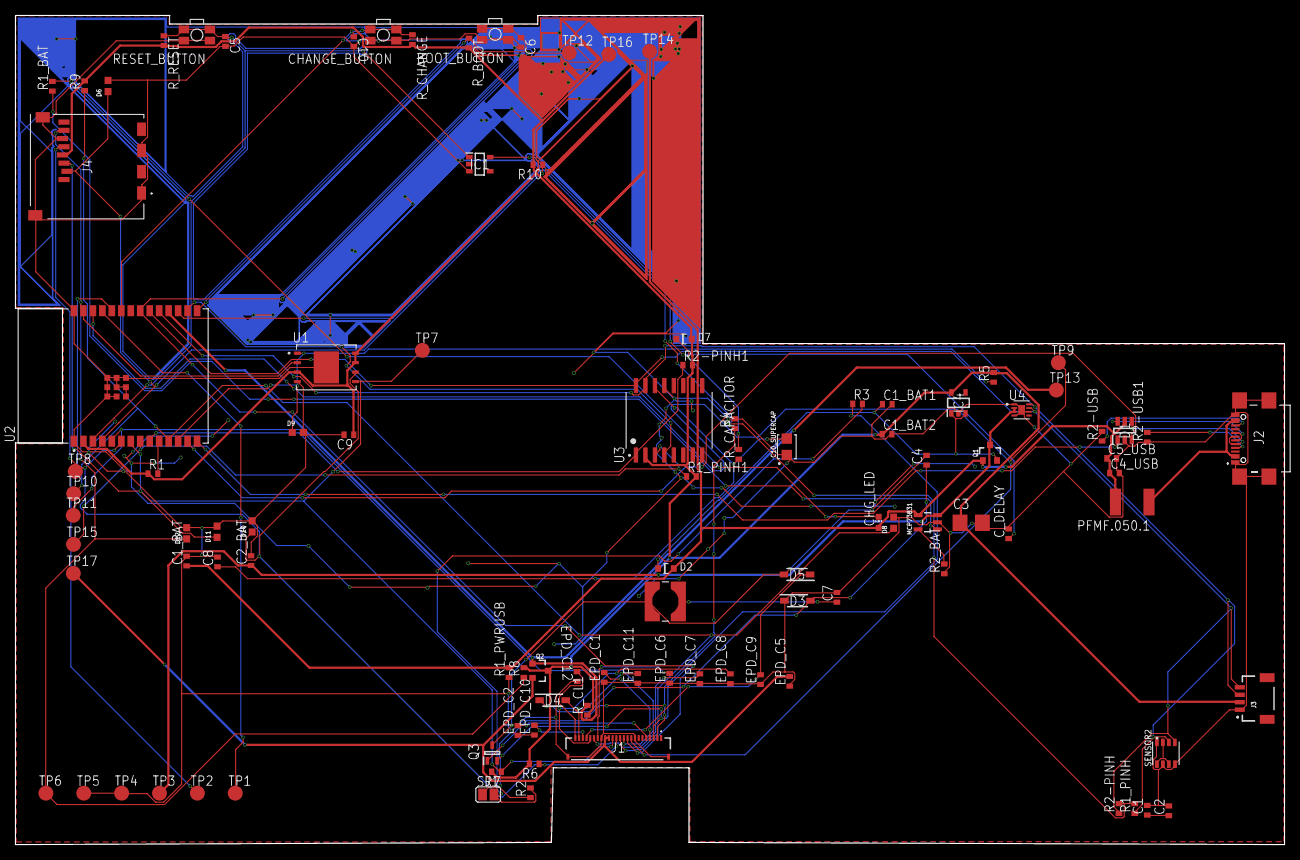
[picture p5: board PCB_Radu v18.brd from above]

Board: 2 copper layers, 170.2 x 111.2 mm, 103 parts (0 on the bottom side), 58 nets.

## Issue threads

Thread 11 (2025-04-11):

README

sammsonn, 2025-04-11:
Diagrama bloc ar fi mai usoara de inteles ca desen, in loc sa fie numai text. De asemenea ar fi folositoare niste explicatii pe sageti
Nu inteleg de ce sunt 2 tabele diferite cu Bill of Materials
A doua tabela de Bill of Materials nu are coloana de datasheet

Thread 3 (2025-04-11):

Schematic - RTC Module

sammsonn, 2025-04-11:
Exista o piesa fara nume (marcata cu 15)

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

RaduRoibu23, 2025-04-15:
bug: in schematicul meu numele piese apare : "R_CAPACITOR"

Closed 2025-04-15.

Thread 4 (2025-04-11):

PCB - Copper Width Errors

sammsonn, 2025-04-11:
Exista 4 erori prezente legate de Copper Width

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

RaduRoibu23, 2025-04-15:
2 erori am reusit sa le rezolv pe cand celalalte 2 nu am gasit solutia lor.

Closed 2025-04-15.

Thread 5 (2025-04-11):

PCB - Board Outline Clearance Errors

sammsonn, 2025-04-11:
Exista 8 erori aprobate legate de Board Outline Clearance

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

RaduRoibu23, 2025-04-15:
Pentru aceste erori a fost luata o decizie la laborator ca le putem ignora.

Closed 2025-04-15.

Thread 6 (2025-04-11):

PCB - Polygon Pour Bottom

sammsonn, 2025-04-11:
Polygon Pour pe layer-ul Bottom nu acopera toata suprafata PCB-ului

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

RaduRoibu23, 2025-04-15:
La fel ca la TOP partea de bottom care apare cu rosu nu a avut la ce sa fie legata pentru a fi GND .

Closed 2025-04-15.

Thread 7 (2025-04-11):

PCB - Polygon Pour Top

sammsonn, 2025-04-11:
Polygon Pour pe layer-ul Top nu acopera toata suprafata PCB-ului
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

RaduRoibu23, 2025-04-15:
Asa am inteles ca trebuie facut. In acele zone partea de GND nu are la ce sa fie legata pentru TOP.

Closed 2025-04-15.

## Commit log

2025-04-06 Update README.md bom
2025-04-15 Update README.md eliminarea 2 BOM

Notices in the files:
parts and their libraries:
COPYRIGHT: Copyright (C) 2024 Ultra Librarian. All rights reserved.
